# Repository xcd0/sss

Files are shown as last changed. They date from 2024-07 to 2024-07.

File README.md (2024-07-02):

# sss

rp2040で作る分割キーボード

- 46キー
- 分割
- カラムスタッガード
- ロータリーエンコーダ
- 狭ピッチ（16.5mm）
- 小型(片手13cmx9cm)
- rp2040
- 3Dプリントケース
- 3Dプリント親指キーキャップ

## 完成予定

sss v7

## 部品

### rp2040を使用した独自ボード

Raspberry Pi Pico が大きく自作キーボードで使いにくいため、同等のボードを作成した。  
とりあえず名前は安直にRPPslimとした。
[@74th](https://x.com/74th)さんの https://74th.booth.pm/items/3929664 が大変参考になった。  





- 30個のGPIO (Raspberry Pi Picoは23個、ProMicroは18個)
- USB-C
- キースイッチより狭い13.3x50mm (Raspberry Pi Picoは21x51mm)
	- GPIOが余分な場合、カットして13.3x30mmまで小さくして使用できる。
	- 上の写真の左は33mmでカットしている。この状態で17個GPIOを使用できる。
- ただし、GNDの数が少なく、両面実装で分厚く(5mm)、おそらく信頼性が低い。

普通rp2040を使用する自作キーボードは、キーボード本体にrp2040をそのまま実装する場合が多い。  
このsssではrp2040を別基板とし、キーボードに対して垂直に配置することでキーボードのサイズを小さくしている。  
また、別基板とすることで、別のキーボードを作る際にも使いまわせる、rp2040の部分に不具合があっても簡単に置き換えられる、ようにした。
 
### ロータリーエンコーダ

[アリエク](https://ja.aliexpress.com/item/1005006333962313.html)で売っているEVQWGD001という水平のロータリーエンコーダを使用。

### 親指用キーキャップ

 [booth](https://xcd0.booth.pm/items/4510462)に転がしている親指キーキャップの高さを少し高くしたものを使用。

### その他のキーキャップ

[Talp](https://talpkeyboard.net/items/5f5444c380933970d139e98c)さんで売っている0.8Uのキーキャップ。  
大体いつもこれを使っている。

## 設計
handwire予定だったが基板も作ることにした。choc対応をやめたら基板がすっきりして作りやすかった。  
### 回路図

### PCB


## ファームウェアのビルド

[tinygo](https://tinygo.org/)と[tinygo-keyboard](https://github.com/sago35/tinygo-keyboard)を使用している。  

Linuxはディストリビューションごとに方法があるので、<https://tinygo.org/getting-started/install/linux/>を参照。  
Macはhomebrewで入る模様。未確認。<https://tinygo.org/getting-started/install/macos/>  

windowsの場合、<https://tinygo.org/getting-started/install/windows/>にある通り、  
[scoop](https://scoop.sh/)経由でコンパイラをインストールするのが良い。

scoopはpowershellで下記のようにインストールできる。
```pwsh
Set-ExecutionPolicy -ExecutionPolicy RemoteSigned -Scope CurrentUser
Invoke-RestMethod -Uri https://get.scoop.sh | Invoke-Expression
```

後は下記のコマンドで、

```pwsh
scoop install go
scoop install tinygo
scoop install make
```
でコンパイラとmakeをインストールし、

```pwsh
cd src
make
```

でコンパイルできる。

## ファームウェアの書き込み

makefileに書いているため、

```
make flash
```

でビルドしつつ書き込むことができる。  
windowsのwslでは書き込めないので注意。  
powershellやmsysからも書き込める。  
BOOTボタンを押しながら抜き差しする必要はない。  

## キーマップ

goのソースコードに定義するとgofmtでフォーマットされて整列した状態を保てないため、  
[hjson形式](https://hjson.github.io/)で記述し、それをビルド前に解釈してキーマップを返す関数を自動生成するようにしている。  
<./src/script/prebuild/prebuild.go>にビルド前に実行されるコードがある。  

- キーマップ内のキーコードは<https://github.com/sago35/tinygo-keyboard/tree/main/keycodes>にあるものを使用する。  
- `lang`に定義した言語を表す文字列がそのままpackage名として使用される。まあ現状jpしかないけれども。  
- 短縮表現を`define`に定義できるようにした。
- `layout`にはレイヤーごとにキーコードを記載する。
	- これは単純に、`[][]string`として読み込まれ、`,`と`\n`区切りの単純な`[][][]string`に解釈される。

```hjson
# キーマップで使用する言語
lang: jp

# キーマップで使用するキーコードの短縮形定義
define: {
	LSFT: KeyLeftShift
	LCTL: KeyLeftCtrl
	LALT: KeyLeftAlt
}

# キーマップ
# レイヤーごとに記述する。
layout: [
	[ # layer 0
		KeyEsc,      Key1,        Key2,        Key3,        Key4,        Key5,        Key6,      Key7,        Key8,        Key9,        Key0,        KeyMinus,    KeyHat,        KeyBackslash,
		KeyTab,      KeyQ,        KeyW,        KeyE,        KeyR,        KeyT,        KeyY,      KeyU,        KeyI,        KeyO,        KeyP,        KeyAt,       KeyLeftBrace,  KeyBackspace,
		LCTL,        KeyA,        KeyS,        KeyD,        KeyF,        KeyG,        KeyH,      KeyJ,        KeyK,        KeyL,        KeySemicolon,KeyColon,    KeyRightBrace, KeyEnter,
		LSFT,        KeyZ,        KeyX,        KeyC,        KeyV,        KeyB,        KeyN,      KeyM,        KeyComma,    KeyPeriod,   KeySlash,    KeyBackslash2,KeyUp,        KeyRightShift,
		KeyMod1,     KeyHankaku,  KeyWindows,  LALT,        KeyMuhenkan, KeySpace,    KeySpace,  KeyHenkan,   KeyHiragana, KeyLeftAlt,  KeyMod1,     KeyLeft,     KeyDown,       KeyRight,
	]
```

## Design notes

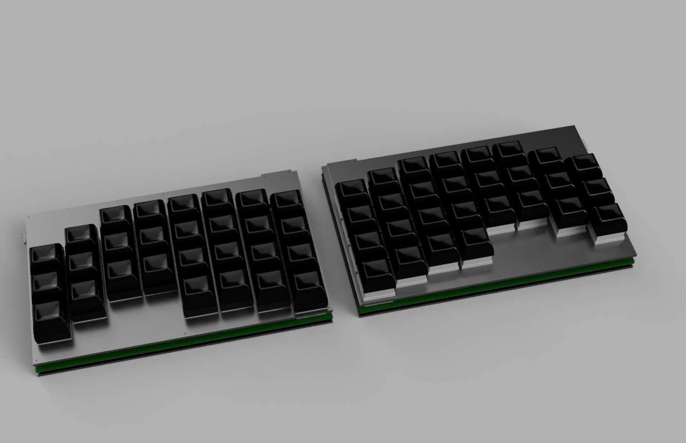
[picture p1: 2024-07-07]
pcb/56/1f2d0ce1-49d8-4178-8e92-21dd92955900.PNG

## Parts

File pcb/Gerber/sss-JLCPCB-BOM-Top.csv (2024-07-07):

Comment | Designator | Footprint | JLCPCB Part# | MFR.Part# | Qty
SW_Push | SW20,SW17,SW7,SW4,SW3,SW16,SW21,SW10,SW14,SW13,SW1,SW11,SW12,SW8,SW22,SW23,SW5,SW2,SW18,SW6,SW15,SW9,SW24 | CherryMX_HotSwap_Narrow |  |  | 23
D | D3,D24,D7,D15,D5,D6,D4,D1,D23,D16,D11,D21,D10,D20,D2,D12,D22,D18,D9,D17,D19,D8,D13,D14 | ll |  |  | 24

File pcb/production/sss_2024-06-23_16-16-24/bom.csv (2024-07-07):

Designator | Footprint | Quantity | Value | LCSC Part #
D1, D10, D11, D12, D13, D14, D15, D16, D17, D18, D19, D2, D20, D21, D22, D23, D24, D3, D4, D5, D6, D7, D8, D9 | ll | 24 | D
J1 | MJ-4PP-9 | 1 | AudioJack4
JP1, JP2, JP3, JP4 | SolderJumper-2_P1.3mm_Open_RoundedPad1.0x1.5mm | 4 | Jumper_2_Open
SW1, SW10, SW11, SW12, SW13, SW14, SW15, SW16, SW17, SW18, SW2, SW20, SW21, SW22, SW23, SW24, SW3, SW4, SW5, SW6, SW7, SW8, SW9 | CherryMX_HotSwap_Narrow | 23 | SW_Push
SW19 | PinHeader_1x02_P2.54mm_Vertical | 1 | SW_Push
U1 | PinHeader_2x06_P2.54mm_Vertical | 1 | ~

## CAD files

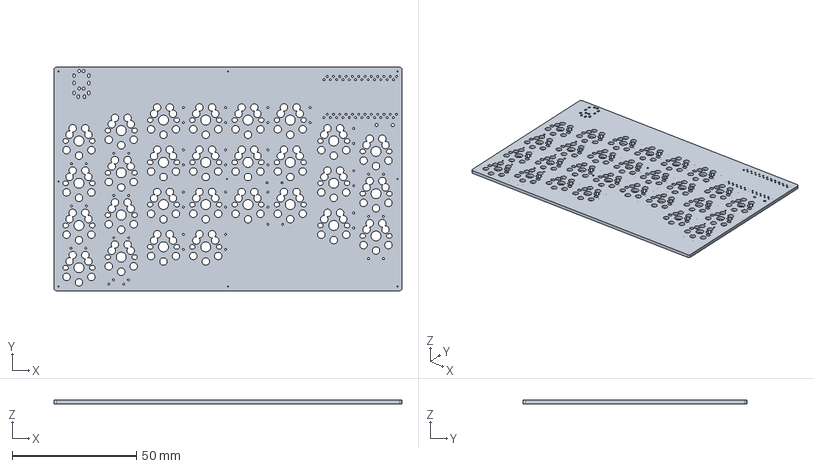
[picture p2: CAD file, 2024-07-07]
pcb/56/56.step
140.0 x 90.0 x 1.60 mm

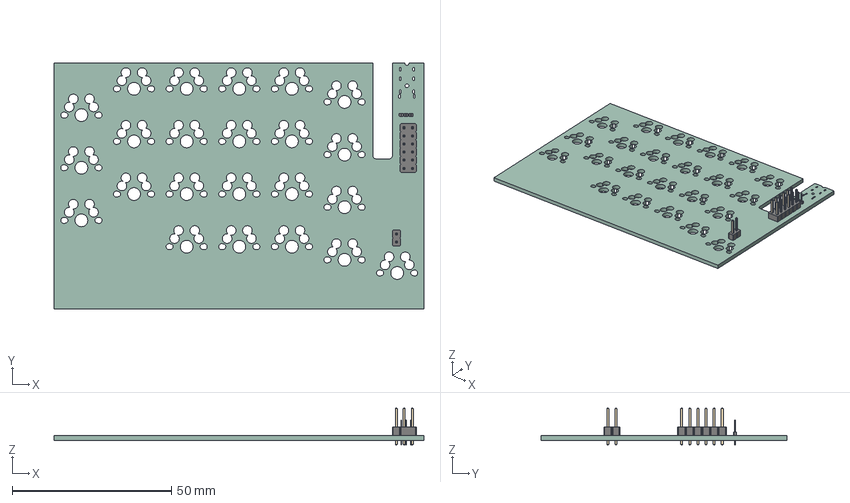
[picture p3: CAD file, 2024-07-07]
pcb/sss.step
116.0 x 77.0 x 11.5 mm
PinHeader_2x06_P254mm_Vertical
PinHeader_1x01_P100mm_Vertical x 3
PinHeader_1x02_P254mm_Vertical
_autosave-sss PCB

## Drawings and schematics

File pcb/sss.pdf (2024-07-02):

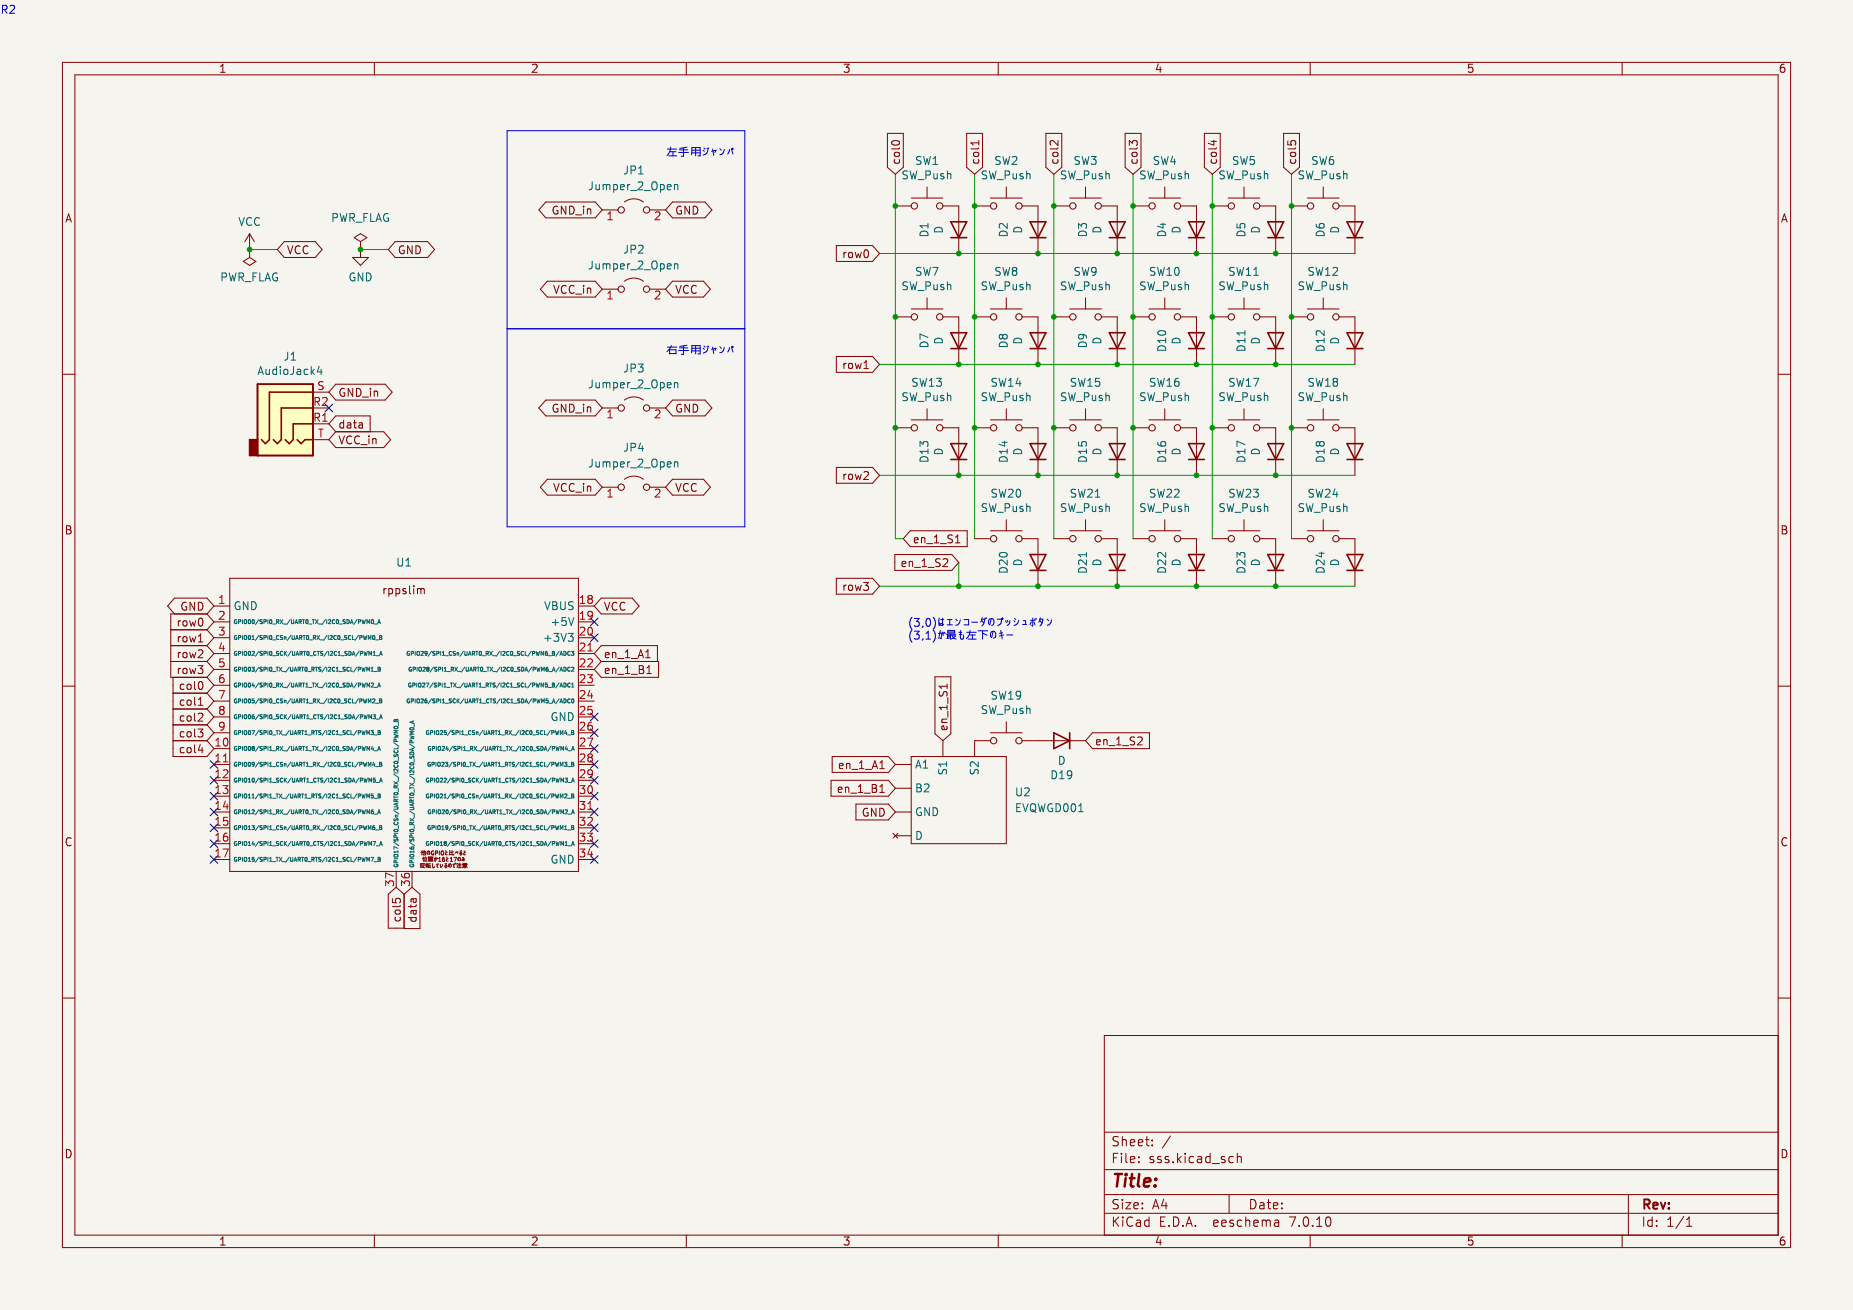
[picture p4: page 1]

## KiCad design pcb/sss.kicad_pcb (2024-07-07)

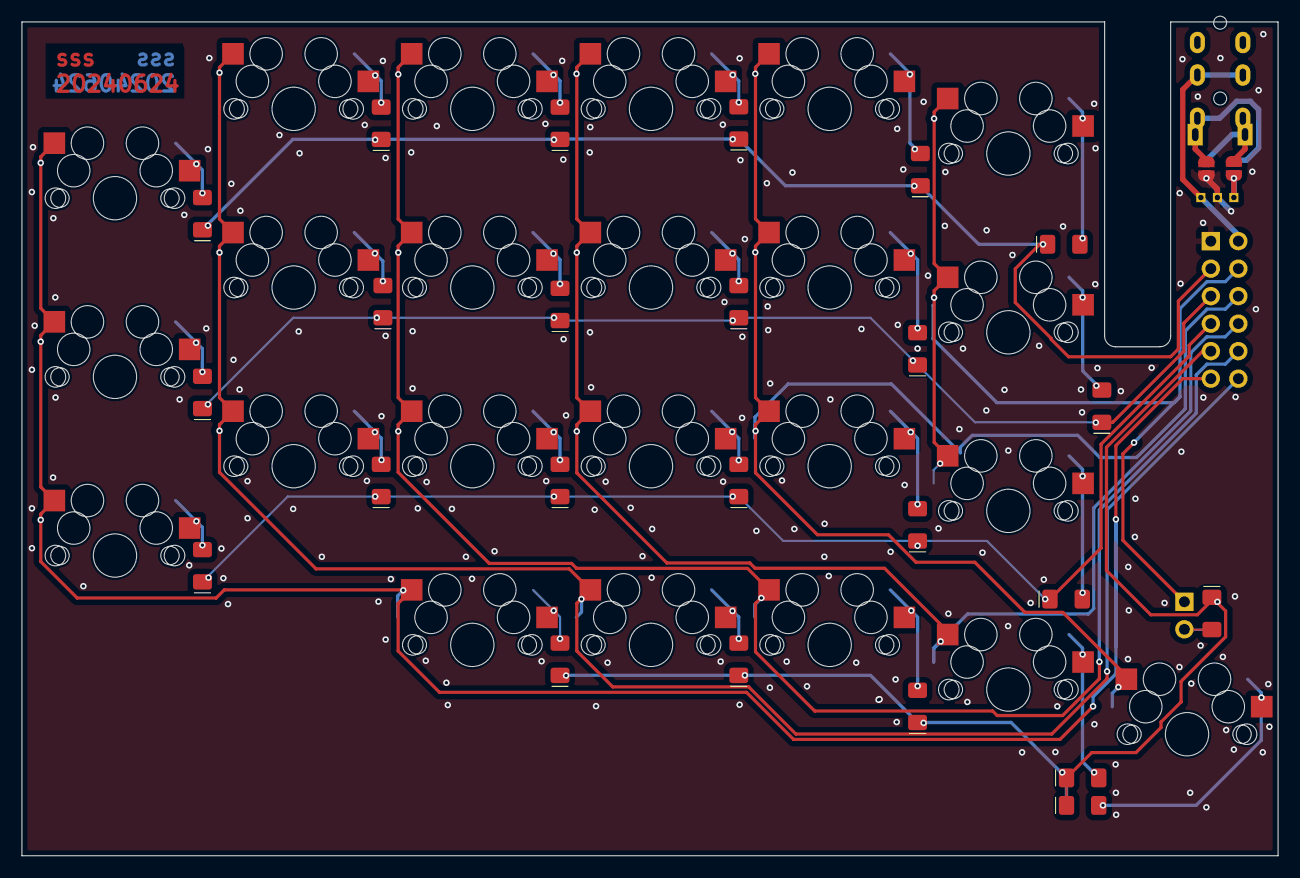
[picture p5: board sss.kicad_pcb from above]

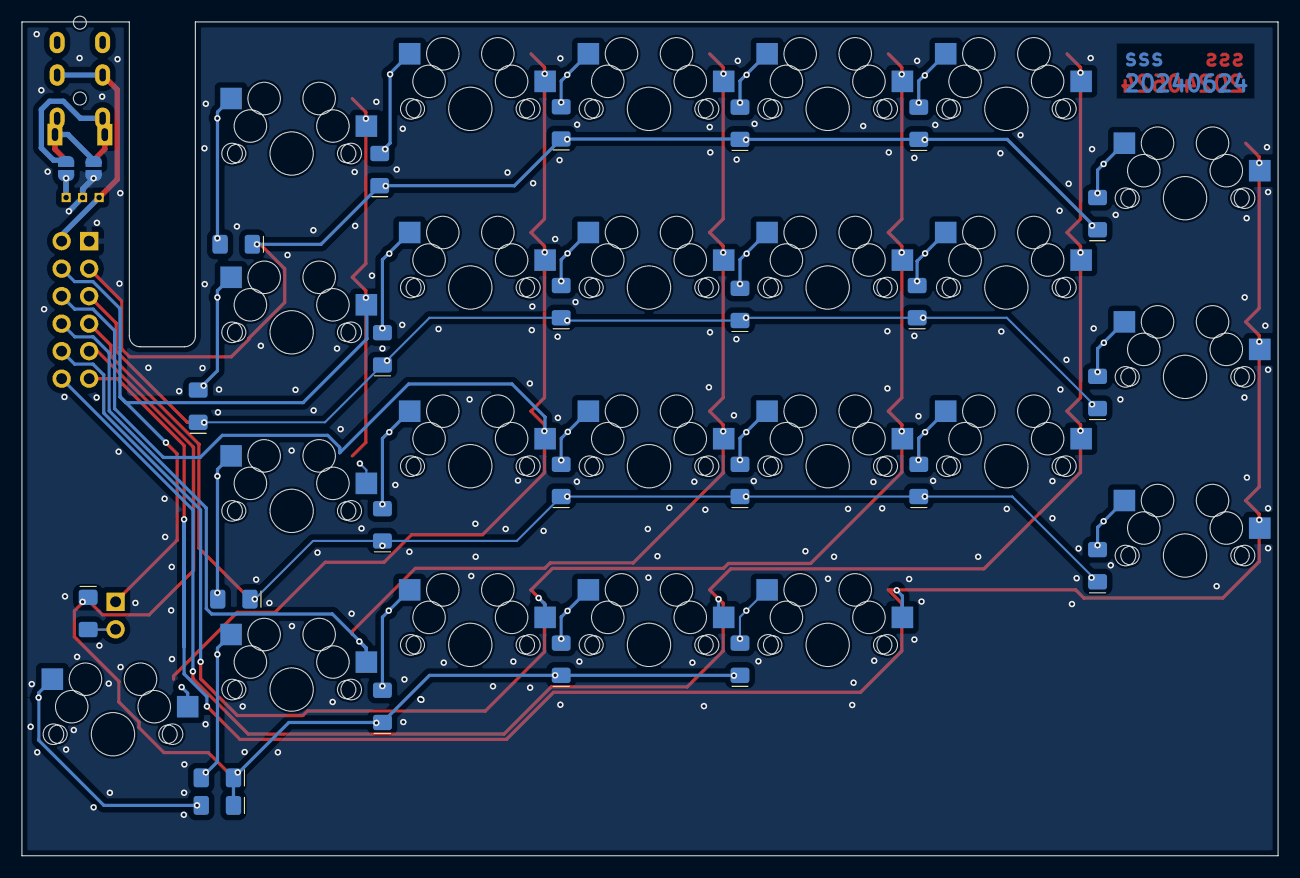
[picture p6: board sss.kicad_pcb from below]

Board: 2 copper layers, 116.0 x 77.0 mm, 54 parts (2 on the bottom side), 39 nets.

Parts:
D1, D2, D3, D4, D5, D6, D7, D8, D9, D10, D11, D12, D13, D14, D15, D16, D17, D18, D19, D20, D21, D22, D23, D24: D; ll
J1: AudioJack4; MJ-4PP-9
JP1, JP2, JP3, JP4: Jumper_2_Open; SolderJumper-2_P1.3mm_Open_RoundedPad1.0x1.5mm
SW1, SW2, SW3, SW4, SW5, SW6, SW7, SW8, SW9, SW10, SW11, SW12, SW13, SW14, SW15, SW16, SW17, SW18, SW20, SW21, SW22, SW23, SW24: SW_Push; CherryMX_HotSwap_Narrow
SW19: SW_Push; PinHeader_1x02_P2.54mm_Vertical
U1: PinHeader_2x06_P2.54mm_Vertical

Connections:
GND: JP1.2 (B), JP3.2 (B), U1.1 (GND)
GND_in: J1.S, JP1.1 (A), JP3.1 (A)
unnamed: D1.2 (A), SW1.2
unnamed: D2.2 (A), SW2.2
unnamed: D3.2 (A), SW3.2
unnamed: D4.2 (A), SW4.2
unnamed: D5.2 (A), SW5.2
unnamed: D6.2 (A), SW6.2
unnamed: D7.2 (A), SW7.2
unnamed: D8.2 (A), SW8.2
unnamed: D9.2 (A), SW9.2
unnamed: D10.2 (A), SW10.2
unnamed: D11.2 (A), SW11.2
unnamed: D12.2 (A), SW12.2
unnamed: D13.2 (A), SW13.2
unnamed: D14.2 (A), SW14.2
unnamed: D15.2 (A), SW15.2
unnamed: D16.2 (A), SW16.2
unnamed: D17.2 (A), SW17.2
unnamed: D18.2 (A), SW18.2
unnamed: D19.2 (A), SW19.2
unnamed: D20.2 (A), SW20.2
unnamed: D21.2 (A), SW21.2
unnamed: D22.2 (A), SW22.2
unnamed: D23.2 (A), SW23.2
unnamed: D24.2 (A), SW24.2
VCC: JP2.2 (B), JP4.2 (B)
VCC_in: J1.T, JP2.1 (A), JP4.1 (A)
col0: SW1.1, SW7.1, SW13.1, SW19.1, U1.8 (GPIO06/SPI0_SCK/UART1_CTS/I2C1_SDA/PWM3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)
col1: SW2.1, SW8.1, SW14.1, SW20.1, U1.9 (GPIO07/SPI0_TX_/UART1_RTS/I2C1_SCL/PWM3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)
col2: SW3.1, SW9.1, SW15.1, SW21.1, U1.10 (GPIO08/SPI1_RX_/UART1_TX_/I2C0_SDA/PWM4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)
col3: SW4.1, SW10.1, SW16.1, SW22.1, U1.11
col4: SW5.1, SW11.1, SW17.1, SW23.1, U1.12
col5: SW6.1, SW12.1, SW18.1, SW24.1, U1.6 (GPIO04/SPI0_RX_/UART1_TX_/I2C0_SDA/PWM2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)
data: J1.R1, U1.7 (GPIO05/SPI0_CSn/UART1_RX_/I2C0_SCL/PWM2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)
row0: D1.1 (K), D2.1 (K), D3.1 (K), D4.1 (K), D5.1 (K), D6.1 (K), U1.2 (GPIO00/SPI0_RX_/UART0_TX_/I2C0_SDA/PWM0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)
row1: D7.1 (K), D8.1 (K), D9.1 (K), D10.1 (K), D11.1 (K), D12.1 (K), U1.3 (GPIO01/SPI0_CSn/UART0_RX_/I2C0_SCL/PWM0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)
row2: D13.1 (K), D14.1 (K), D15.1 (K), D16.1 (K), D17.1 (K), D18.1 (K), U1.4 (GPIO02/SPI0_SCK/UART0_CTS/I2C1_SDA/PWM1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)
row3: D19.1 (K), D20.1 (K), D21.1 (K), D22.1 (K), D23.1 (K), D24.1 (K), U1.5 (GPIO03/SPI0_TX_/UART0_RTS/I2C1_SCL/PWM1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)

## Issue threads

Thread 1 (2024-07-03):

AddMatrixKeyboardが動作していない

xcd0, 2024-07-03:
d.AddMatrixKeyboard(col, row, GetKeycodes())
のようにしているが、実機だと反応していないように見える。

検証する。

xcd0, 2024-07-03:
とりあえずraspberry pi picoと簡単な回路でやってみる。

xcd0, 2024-07-06:
下記のためclose

https://twitter.com/xcd0/status/1809520578539450576

Closed 2024-07-06.

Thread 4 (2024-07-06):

MatrixKeyboardの入出力ピン設定

xcd0, 2024-07-06:
AddMatrixKeyboardで
https://github.com/sago35/tinygo-keyboard/blob/066aa2b85a5328ec588497ea14d9894261f43cf4/kbmatrix.go#L27-L32
```go
	for c := range colPins {
		colPins[c].Configure(machine.PinConfig{Mode: machine.PinInputPulldown})
	}
	for r := range rowPins {
		rowPins[r].Configure(machine.PinConfig{Mode: machine.PinInputPulldown})
	}
```
で設定しているのに
https://github.com/sago35/tinygo-keyboard/blob/066aa2b85a5328ec588497ea14d9894261f43cf4/kbmatrix.go#L74-L86
```go
func (d *MatrixKeyboard) Get() []State {
	for c := range d.Col {
		for r := range d.Row {
			//d.State[r*len(d.Col)+c] = d.Row[r].Get()
			current := false
			if !d.options.InvertDiode {
				d.Col[c].Configure(machine.PinConfig{Mode: machine.PinOutput})
				d.Col[c].High()
				current = d.Row[r].Get()
			} else {
				d.Row[r].Configure(machine.PinConfig{Mode: machine.PinOutput})
				d.Row[r].High()
				current = d.Col[c].Get()
			}
```
のようにキースキャン1回ごとに出力ピンを設定している

入出力を切り替える必要があるDuplexや改良二乗マトリクスでは必要だと思われるが、
一方方向にしかスキャンしない一般のキーマトリクスでは不要に思われる。

AddMatrixKeyboardで
```go
	if !d.options.InvertDiode { // COL2ROW
		for c := range colPins {
			colPins[c].Configure(machine.PinConfig{Mode: machine.PinOutput})
		}
		for r := range rowPins {
			rowPins[r].Configure(machine.PinConfig{Mode: machine.PinInputPulldown})
		}
	} else { // ROW2COL
		for c := range colPins {
			colPins[c].Configure(machine.PinConfig{Mode: machine.PinInputPulldown})
		}
		for r := range rowPins {
			rowPins[r].Configure(machine.PinConfig{Mode: machine.PinOutput})
		}
	}
```
のように設定してはダメだろうか。

xcd0, 2024-07-06:
何か問題があるのかもしれない

xcd0, 2024-07-06:
やってみたらVppが半分以下？になった
何か効果がある模様

Closed 2024-07-06.
